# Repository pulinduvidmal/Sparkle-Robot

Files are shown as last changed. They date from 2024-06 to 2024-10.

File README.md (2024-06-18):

# Sparkle Robot ✨🤖

The Sparkle Robot is an advanced automation marvel engineered with the Arduino Mega 2560 at its core. This third-semester project for the EN2533 Robot Design and Competition module showcases a suite of dynamic features that highlight its versatility in robotics engineering.

🚀 **Exciting Robotics Achievement Unlocked: EN2533 Module Conquered!** 🤖

We are delighted to share the successful completion of the EN2533 Robot Design and Competition module in semester 3! 🌟 Our journey was filled with diverse challenges, where my team and I showcased our technical prowess and innovative solutions.

<div style="text-align: center;">
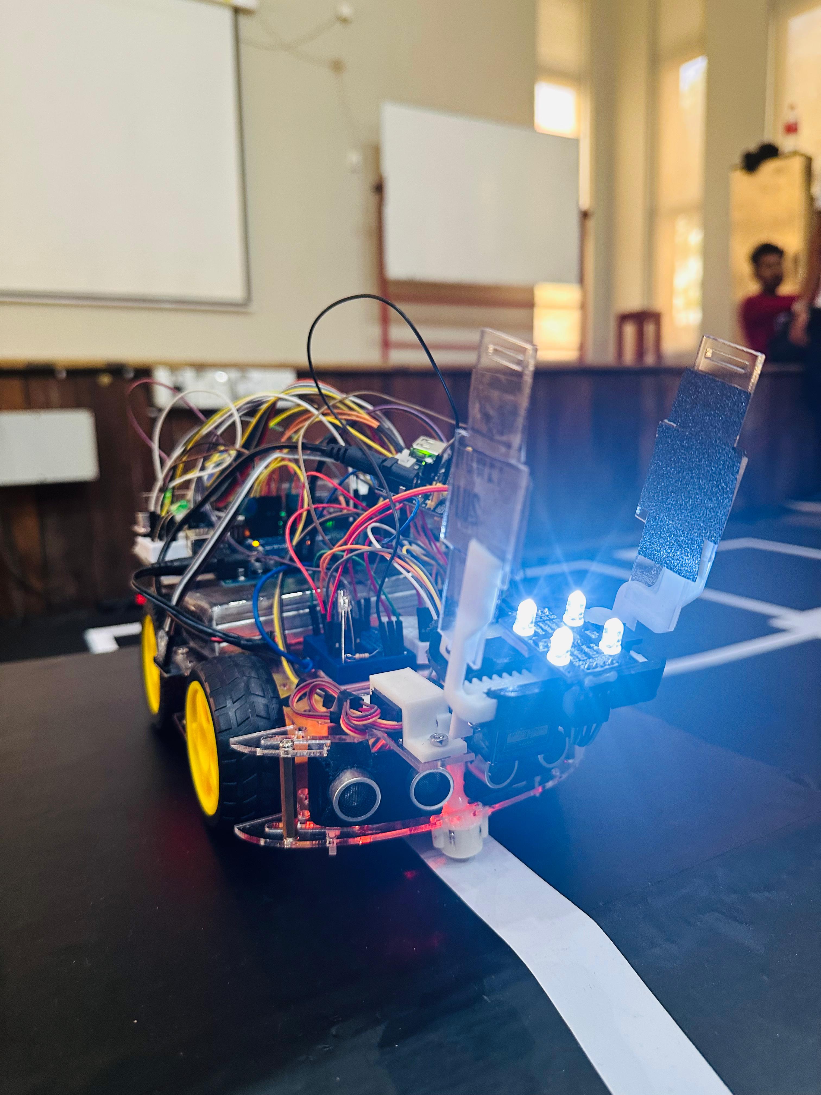
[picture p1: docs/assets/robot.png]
New Image
  
</div>

## Features 🌟

### 1. Line Following and Obstacle Avoidance 🚧
The Sparkle Robot is adept at navigating a designated path with precision. It can follow lines with agility, making sharp turns and avoiding obstacles in its path without human intervention.

### 2. Ramp Navigation & Box Dragging 📦
Demonstrating its mechanical prowess, the robot can traverse inclined surfaces and even engage in box dragging activities. This function highlights the robot's capability to adapt to physical tasks and solve problems autonomously.

### 3. Box Picking and Color Detection 🎨
With an arm engineered in SolidWorks and powered by a servo mechanism, the robot can perform complex picking tasks. It is also equipped with a color sensor strategically positioned to detect and differentiate colors during the pick-up process.

### 4. Maze Solving 🌀
The Sparkle Robot employs a logical approach to navigate mazes. It uses the left-hand rule algorithm to find its way through mazes, identifying the correct path based on the color of the box it carries, and places it accurately in a predetermined location.

### 5. Sound Detection 🎤
Incorporating advanced auditory processing capabilities, the robot can respond to sound cues. This feature allows it to execute precise stops and movements in response to specific sounds, enhancing its interactive abilities.

## Getting Started 🛠️

To get started with the Sparkle Robot, follow these instructions:

1. **Clone the Repository**
   ```bash
   git clone https://github.com/your-username/sparkle-robot.git
   ```

2. **Navigate to the Directory**
   ```bash
   cd sparkle-robot
   ```

3. **Upload the Code to Arduino Mega 2560**
   - Open the Arduino IDE.
   - Load the `sparkle_robot.ino` file.
   - Select the correct board and port.
   - Upload the code.

## Hardware Requirements 🛒

- Arduino Mega 2560
- Line sensors
- Ultrasonic sensors
- Servo motors
- Color sensor
- Sound sensor
- Chassis with wheels
- Box for dragging and picking

## Team Members

- [**Akhila Prabodha**](https://github.com/AkhilaPrabodha)
- [**Pulindu Vidmal**](https://github.com/pulinduvidmal)
- [**Navini Jagoda**](https://github.com/Navini11)
- [**Eshan Surendra**](https://github.com/eshansurendra)
- [**Achira Hansindu**](https://github.com/achira1428gsd)
  
## Demo

https://github.com/pulinduvidmal/Sparkle-Robot/assets/107745680/13c5de56-0cc0-490a-96d4-449374089251

# Contributions 🤝

Contributions are welcome! 

- **Bug Fixes:** If you find any bugs or issues, feel free to create an issue or submit a pull request.
- **Feature Enhancements:** If you have ideas for new features or improvements, don't hesitate to share them.

Feel free to reach out with any questions or suggestions!

# License 📄

This project is licensed under the [MIT License](LICENSE).

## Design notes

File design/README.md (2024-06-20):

## Sparkle- Robot-Design

This folder contains SolidWorks STL files for 3D printing the components of the Sparkle Robot Arm. These files are designed for use with a variety of 3D printing technologies and materials.

**Component Breakdown:**

* **1_hand.STL:** This file represents the first component of the robot hand.
* **2_hand.STL:** This file represents the second component of the robot hand.
* **arm small box.STL:** This file represents a small box situated on the robot arm to keep mechanism with servo motor.
* **wheel final.STL:** This file represents a final version of a wheel component used on the robot arm, for locomotion.

**File Usage:**

* These STL files can be imported into any 3D printing software to prepare for printing.
* Users are encouraged to review the file names and orientations carefully before printing.
* It is recommended to use a slicing software compatible with your 3D printer to prepare the files for printing. 
* Choose appropriate print settings and material based on your printer's capabilities and the desired mechanical properties of the printed parts.

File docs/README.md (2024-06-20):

# Sparkle-Robot 🤖

This repository includes the complete source code, design files, and documentation for the Sparkle Robot, a versatile and feature-rich automation platform built for the EN2533 - Robot Design and Competition module.

<div align="center">
  New Image
</div>

## Features

* **Line Following & Obstacle Avoidance 🚧:** Enables the robot to navigate predefined paths while avoiding obstacles using phototransistors and ultrasonic sensors.
* **Ramp Navigation & Box Dragging 📦:**  A robust mechanical design with a geared motor system enables the robot to ascend ramps and drag boxes.
* **Box Picking & Color Detection 🎨:** A custom SolidWorks-designed robotic arm, powered by a servo motor, allows for precise box picking. A color sensor integrated into the arm enables the robot to differentiate between different colored boxes.
* **Maze Solving 🌀:** Employs a `left-hand rule algorithm`, guided by color sensing, to navigate mazes. The robot utilizes the box color to determine the correct path and destination within a maze environment.
* **Sound Detection 🎤:** Incorporates an audio sensor that allows the robot to detect and respond to specific sound cues, enabling dynamic interactions and programmed actions based on sound triggers.

## Repository Structure

```
├── design
├── docs
│   └── assets
|   └── requirements
├── src
└── scripts
```

**Detailed Description:**

* **design/Robot-Arm-STL:** Contains STL files for 3D printing the robotic arm components designed using SolidWorks.
* **docs**
    * **assets:** Contains supplementary assets for documentation, such as images, diagrams, and videos.
    * **requirements:**  Contains competition requirements documents for the EN2533 module. This folder should include:
        * **Task_v1.pdf:**  The initial version of the competition guidebook.
        * **Task_v1.1.pdf:**  An updated version of the competition guidebook with revisions and clarifications.
* **src:**  contains the Arduino source code for the Sparkle Robot.
    * **sparkle_robot_src.ino:**  The main Arduino program that controls all the robot functionalities.
* **scripts:** Contains scripts for each hardware part of robot for test their funcationality separately.

## Task - 2023

> [!TIP]
> The full task documentation can be found in the [requirements](/docs/requirements/) folder.
> - [Task_V1.0](/docs/requirements/EN2533-Robot_Designand_Competition_Task_v1.0.pdf)
> - [Task_V1.1](/docs/requirements/EN2533-Robot_Design_and_Competition_Task_v1.1.pdf)

<div align="center">
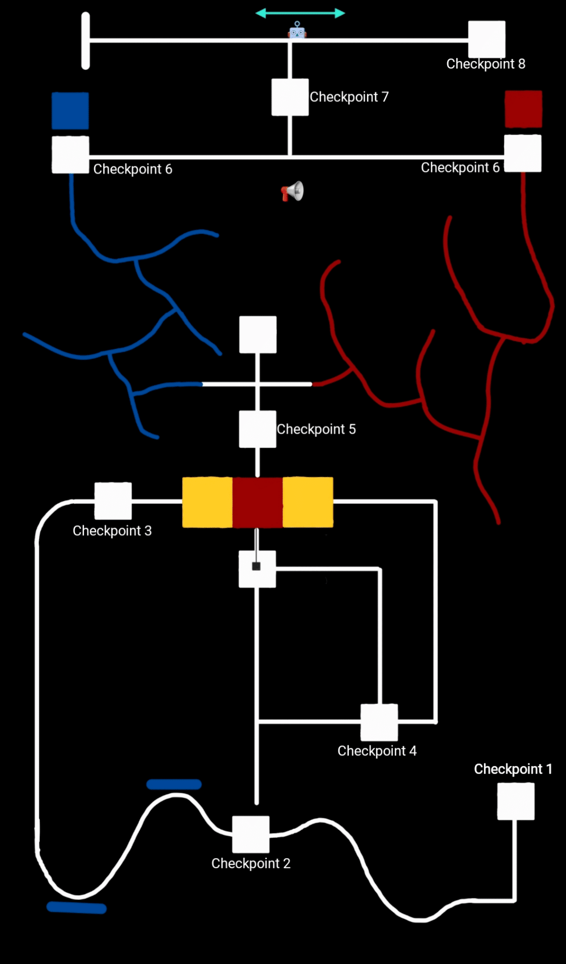
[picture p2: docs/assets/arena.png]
Arena New Image
  
</div>

## Robot overview

### Adding Functionality

* **Line Following:**
    * Implement a line-following algorithm using ir array.
    * Use the analogRead() function to read sensor values.
    * Implement a PID (Proportional-Integral-Derivative) controller to maintain a stable line-following trajectory.
* **Obstacle Avoidance:**
    * Utilize ultrasonic sensors to detect obstacles in front of the robot.
    * Implement a basic obstacle avoidance logic to stop or steer the robot away from detected objects.
* **Ramp Navigation:**
    * Ensure a robust mechanical design that can handle the weight and friction of ascending ramps.
    * Implement a motor control algorithm that can adjust motor speeds to smoothly navigate ramps.
* **Box Dragging:**
    * Design a mechanism that allows the robot to grip and drag boxes without dropping them.
    * Implement a motor control system that can accurately control the speed and direction of the dragging motion.
* **Box Picking & Color Detection:**
    * Design a robotic arm in SolidWorks with appropriate dimensions and articulation.
    * Utilize a servo motor to control the arm movement and gripping mechanism.
    * Integrate a color sensor into the arm's gripping mechanism to detect the color of the box.
* **Maze Solving:**
    * Implement the left-hand rule algorithm to navigate mazes.
    * Use the color sensor to identify the correct path based on the color of the box being carried.
    * Develop logic to determine the correct destination for placing the box.
* **Sound Detection:**
    * Utilize an audio sensor to detect specific sound cues.
    * Implement logic to trigger specific actions or movements based on detected sounds.

### Hardware Requirements

**Sensors:**

* **[Raykha S8 – TCRT5000 based 8 channel Reflective Sensor Array:](https://aptinex.com/product/raykha-s8/)**
    * **Function:** Line detection and color differentiation.
    * **Application:** Line following.
* **[HC-SR04 Ultrasonic Sensors](https://lastminuteengineers.com/arduino-sr04-ultrasonic-sensor-tutorial/):**
    * **Function:** Distance measurement.
    * **Application:** Obstacle detection, object picking, and guarding.
* **[TCS230 RGB Color Recognition Sensor](https://randomnerdtutorials.com/arduino-color-sensor-tcs230-tcs3200/):**
    * **Function:** Color detection and differentiation.
    * **Application:** Competition box object colors identification.
* **[MAX9814 Electret Microphone Amplifier Stable Module with Auto Gain Control](https://www.phippselectronics.com/using-the-max9814-microphone-amplifier-module-with-arduino/):**
    * **Function:** Sound detection and threshold adjustment using [arduinoFFT](https://github.com/kosme/arduinoFFT) library.
    * **Application:** Interactive functionality, event triggering.
* **[MPU6050 Accelerometer and Gyroscope](https://lastminuteengineers.com/mpu6050-accel-gyro-arduino-tutorial/):**
    * **Function:** 3-axis motion tracking.
    * **Application:** Motion tracking, orientation sensing.
      
**Actuators:**

* **DC Gear Motors (34:1 metal gear motors):**
    * **Voltage:** 12V
    * **Application:** Linear motion, driving wheels, and providing torque.
      
* **Servo Motors (MG996R metal gear high torque servo motors):**
    * **Voltage:** 6V
    * **Rotation:** 180 degrees
    * **Application:**  Robotic arm movement, gripping mechanisms, and slider operation.

**Power and Battery:**

* **Battery:** 3S 5200mAh 40C 11.1v LiPo battery.
* **Power Management:**
    * **Step-down buck converter (LM2596S):**  Reduces battery voltage to 9V for motor driver module operation.
    * **Independent buck converter:**  Converts voltage to 5V for sensor functionality.

**Indicators:**

* **LEDs:**  Indicate infrared sensor status and provide visual feedback on sensor operation.

**Other Components:**

* **Power Switch:**  Enables on/off control of the entire robot system.
* **Task-Specific Switches:**  Control activation of specific robot functionalities during competition tasks.

**Robot Arm and Mechanisms:**

* The robot arm is designed in SolidWorks and is powered by a servo motor.
* The arm is responsible for picking up and placing boxes, and it incorporates a color sensor for identifying box colors.
* Gripping mechanisms and slider operations are controlled by servo motors, enabling precise manipulation of objects.

**Software:**

* **[Arduino Mega 2560](https://docs.arduino.cc/hardware/mega-2560/):**  The main microcontroller that controls all robot functionalities.
* **Source Code:**  The code for the Sparkle Robot is located in the `src` folder. The main program file is `sparkle_robot_src.ino`.

> [!TIP]
> Individual hardware components and their functionalities can be independently verified using dedicated test scripts located within the `scripts` folder.

> [!WARNING]
> Modifying hardware component connections or device configurations will inevitably necessitate adjustments to the corresponding pin configurations within the source code or scripts.
## Team Members

- [**Akhila Prabodha**](https://github.com/AkhilaPrabodha)
- [**Pulindu Vidmal**](https://github.com/pulinduvidmal)
- [**Navini Jagoda**](https://github.com/Navini11)
- [**Eshan Surendra**](https://github.com/eshansurendra)
- [**Achira Hansindu**](https://github.com/achira1428gsd)
  
## Demo

https://github.com/pulinduvidmal/Sparkle-Robot/assets/107745680/13c5de56-0cc0-490a-96d4-449374089251

## Contributions

Contributions are welcome! 

- **Bug Fixes:** If you find any bugs or issues, feel free to create an issue or submit a pull request.
- **Feature Enhancements:** If you have ideas for new features or improvements, don't hesitate to share them.

Feel free to reach out with any questions or suggestions!

# License

This project is licensed under the [MIT License](LICENSE).

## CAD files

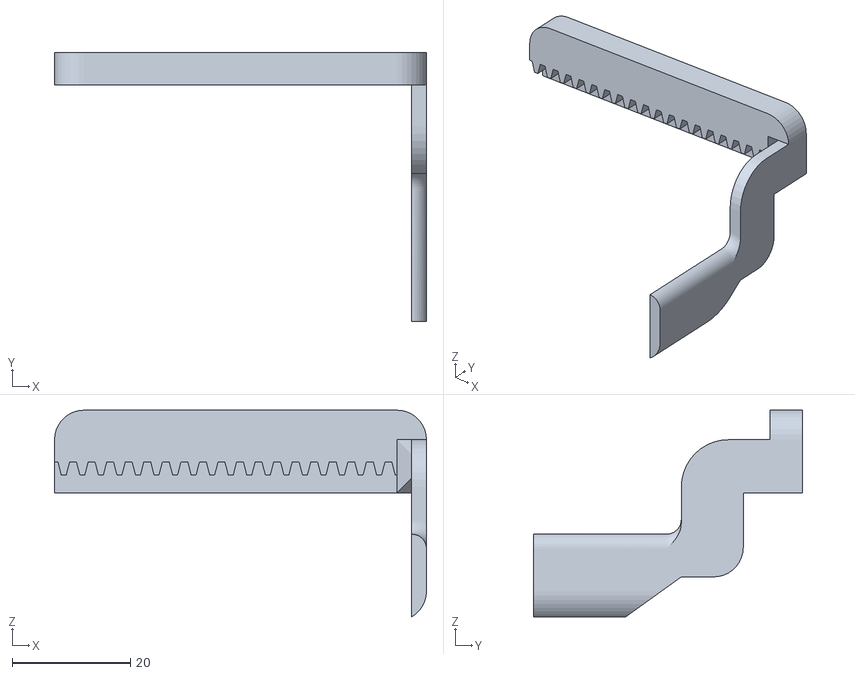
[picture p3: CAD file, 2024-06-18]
design/Robot-Arm-STL/2_hand.STL
63.0 x 45.5 x 35.0

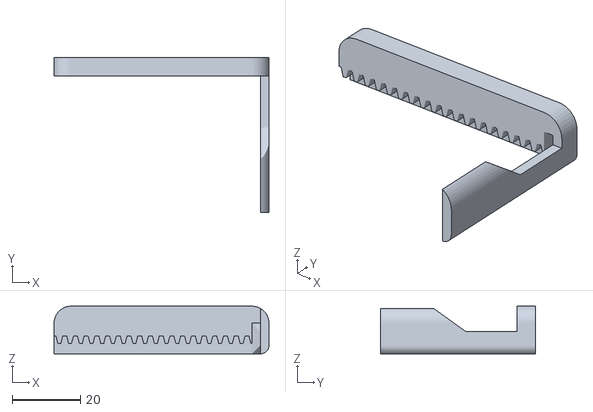
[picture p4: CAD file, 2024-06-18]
design/Robot-Arm-STL/1_hand.STL
63.0 x 45.5 x 14.0

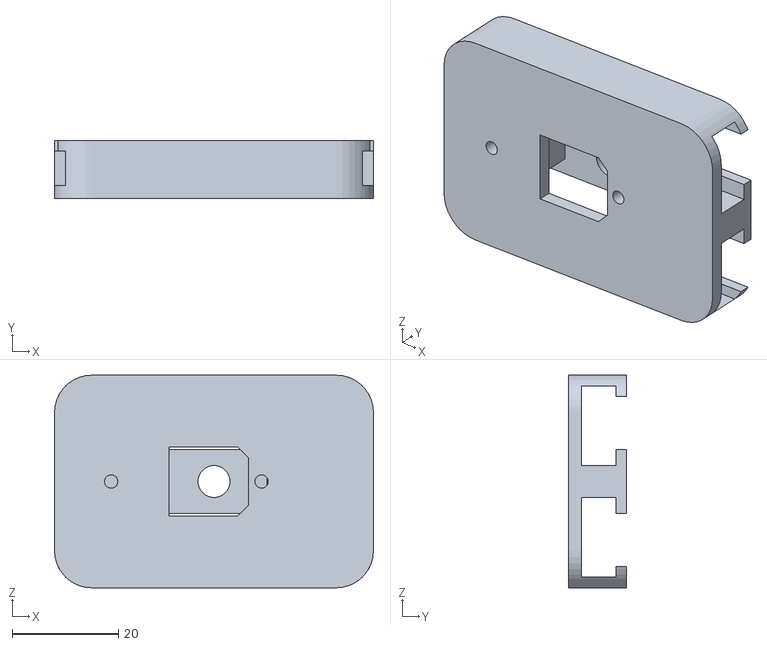
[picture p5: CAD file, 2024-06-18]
design/Robot-Arm-STL/arm small box.STL
60.0 x 11.0 x 40.0

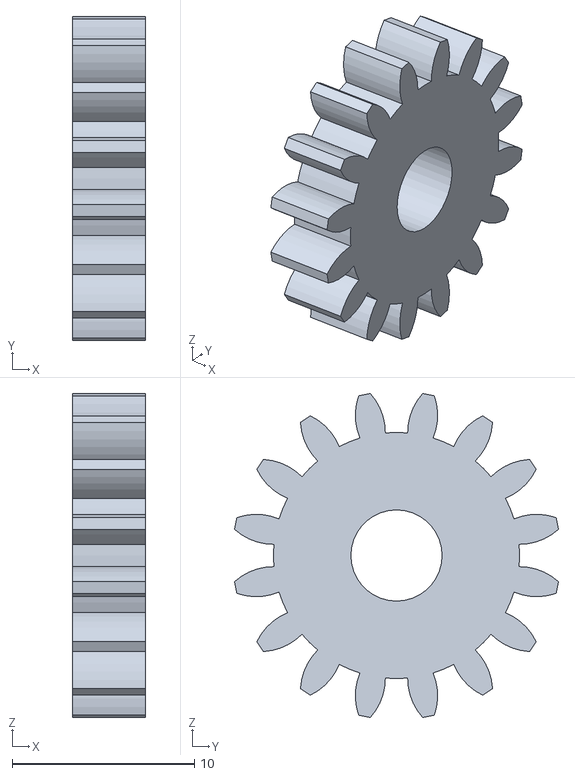
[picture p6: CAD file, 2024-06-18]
design/Robot-Arm-STL/wheel final.STL
4.00 x 17.8 x 17.8

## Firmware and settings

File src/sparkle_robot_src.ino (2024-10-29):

#include <L298N.h>
#include <Arduino.h>
#include <Servo.h>
#include "arduinoFFT.h"

Servo arm;
Servo hand;
arduinoFFT FFT;

//////////////
// Have to redefine those below pins as we plugged
#define AIN1 49
#define BIN1 51
#define AIN2 47
#define BIN2 53
#define PWMA 3
#define PWMB 4
//motor1=right
////////

//ultrasonic sensor read
//////ultrasonic pins
#define lftrig 10
#define lfecho 11
#define rftrig 8
#define rfecho 9

// Initializing motors.  The library will allow you to initialize as many
// motors as you have memory for.  If you are using functions like forward
// that take 2 motors as arguements you can either write new functions or
// call the function more than once.
L298N motor1(PWMA, AIN1, AIN2);
L298N motor2(PWMB, BIN1, BIN2);

// Assign pin numbers to each servo
const int armPin = 12;
const int handPin = 13;

// Constants
const int SensorCount = 8; // Total number of sensors
const int analogSensorCount = 8; // Number of analog sensors
const int analogSensorPins[analogSensorCount] = {A15, A14, A13, A12, A11, A10, A9, A8}; // Analog pins for the remaining sensors
int IR_weight[8] = { -50, -30, -15, -5, 5, 15, 30, 50};
float errorArray[50] = {0};
int sensorValues[SensorCount];

// PID control parameters
float Kp = 4 ; // Proportional term
float Ki = 0; // Integral term
float Kd = 15; // Derivative term
float sum;
int increment_count = 0;
int wall_count = 0;
long ldistance;
long rdistance;

float error;

// PID variables
float P, I, D, previousError = 0;

float lsp, rsp;
int lfspeed = 95;

//////Mic
const int microphonePin = A4;  // Adjust the pin according to your setup

const uint16_t samples = 64;  // This value MUST ALWAYS be a power of 2
const double samplingFrequency = 5000;
const int detectionDuration = 5000;  // Adjust as needed (in milliseconds)

const double detectionMinFrequency = 560;  // Adjust based on your environment
const double detectionMaxFrequency = 600;  // Adjust based on your environment
double averageFrequency;
double currentFrequency;

#define stopLED 39
#define goLED 37

unsigned long lastDetectionTime = 0;

double vReal[samples];
double vImag[samples];

const int maxStoredValues = 30;  // Adjust based on your needs
double storedFrequencies[maxStoredValues];
double storedFrequenciesSub[5];
int storedValuesIndex = 0;
//////////////////////////

// Function prototypes
void readSensors(int *values);
float calculatePID(int *sensorValues);
void motor_drive(int left, int right);
void turnLeft(int *sensorValues);
void turnRight(int *sensorValues);
void noLine();
//Maze
void turnLeft_maze(int *sensorValues);
void turnRight_maze(int *sensorValues);
void noLine_maze();
void maze(int *sensorValues);
void towards_box(int *sensorValues);

void setup() {
  // Initialize analog sensor pins as input
  for (int i = 0; i < analogSensorCount; i++) {
    pinMode(analogSensorPins[i], INPUT);
  }

  // Initialize motor driver pins
  pinMode(PWMA, OUTPUT);
  pinMode(AIN1, OUTPUT);
  pinMode(AIN2, OUTPUT);
  pinMode(PWMB, OUTPUT);
  pinMode(BIN1, OUTPUT);
  pinMode(BIN2, OUTPUT);
  pinMode(23, OUTPUT);
  pinMode(25, OUTPUT);
  pinMode(8, OUTPUT);

  pinMode(lftrig, OUTPUT);
  pinMode(lfecho, INPUT);
  pinMode(rftrig, OUTPUT);
  pinMode(rfecho, INPUT);

  // Start with motors stopped
  motor1.stop();
  motor2.stop();
  digitalWrite(23, LOW);
  digitalWrite(25, LOW);
  //Servo
  arm.attach(armPin);
  hand.attach(handPin);
  zip_mode();

  pinMode(stopLED, OUTPUT);
  pinMode(goLED, OUTPUT);

  digitalWrite(goLED, LOW);
  digitalWrite(stopLED, LOW);

  Serial.begin(9600);
}

void loop() {
  readSensors(sensorValues);
  lUltrasonic_read();
  rUltrasonic_read();
  if (increment_count == 0) {
    if (sensorValues[0] == 1 && sensorValues[1] == 1 && sensorValues[2] == 1 && sensorValues[3] == 1 && sensorValues[4] == 1 && sensorValues[5] == 1 && sensorValues[6] == 1 && sensorValues[7] == 1) {
      increment(sensorValues);
    }
  }
  else if (increment_count == 1) {
    if (sensorValues[0] == 1 && sensorValues[1] == 1 && sensorValues[2] == 1 && sensorValues[3] == 1 && sensorValues[4] == 1 && sensorValues[5] == 1 && sensorValues[6] == 1 && sensorValues[7] == 1) {
      motor1.stop();
      motor2.stop();
      motor1.setSpeed(85);   // Set right motor speed
      motor1.backward();       // Move right motor forward
      motor2.setSpeed(85);   // Set left motor speed
      motor2.forward();
      delay(80);
      motor1.stop();
      motor2.stop();
      increment(sensorValues);
    }
    else {
      line_follow(sensorValues);
    }
  }
  else if (increment_count == 2) {
    if (sensorValues[0] == 1 && sensorValues[1] == 1 && sensorValues[2] == 1 && sensorValues[3] == 1 && sensorValues[4] == 1 && sensorValues[5] == 1 && sensorValues[6] == 1 && sensorValues[7] == 1) {
      increment(sensorValues);
    }
    else {
      wall_follow(sensorValues);
    }
  }
  else if (increment_count == 3) {
    if (sensorValues[0] == 1 && sensorValues[1] == 1 && sensorValues[2] == 1 && sensorValues[3] == 1 && sensorValues[4] == 1 && sensorValues[5] == 1 && sensorValues[6] == 1 && sensorValues[7] == 1) {
      increment(sensorValues);
    }
    else {
      line_follow(sensorValues);
    }
  }
  else if (increment_count == 4) {
    motor1.stop();
    motor2.stop();
    delay(15000);
  }
  else {
    motor1.stop();
    motor2.stop();
    delay(15000);
  }
}

void increment(int *sensorValues) {
  motor1.stop();
  motor2.stop();
  delay(2000);
  white(sensorValues);

}

void increment_back(int *sensorValues) {
  motor1.stop();
  motor2.stop();
  delay(500);
  white_back(sensorValues);

}

void line_follow(int *sensorValues) {
  if (isImmediateTurn(sensorValues)) {
    motor1.stop();
    motor2.stop();
    //digitalWrite(26, HIGH);
    //delay(2000);
    turn(sensorValues);
  }
  else if (sensorValues[0] == 0 && sensorValues[1] == 0 && sensorValues[2] == 0 && sensorValues[3] == 0 && sensorValues[4] == 0 && sensorValues[5] == 0 && sensorValues[6] == 0 && sensorValues[7] == 0) {
    motor1.stop();
    motor2.stop();
    digitalWrite(30, HIGH);
    noLine(sensorValues);
    //digitalWrite(8, LOW);
  }
  else {

    float pidValue = calculatePID(sensorValues);
    PID_Linefollow(pidValue);

    // You may adjust the delay for performance tuning
    digitalWrite(26, LOW);
    digitalWrite(28, HIGH);
    digitalWrite(30, LOW);
  }
}

void line_follow_back(int *sensorValues) {
  if (isImmediateTurn(sensorValues)) {
    motor1.stop();
    motor2.stop();
    digitalWrite(26, HIGH);
    //delay(2000);
    turn(sensorValues);
  }
  else if (sensorValues[0] == 0 && sensorValues[1] == 0 && sensorValues[2] == 0 && sensorValues[3] == 0 && sensorValues[4] == 0 && sensorValues[5] == 0 && sensorValues[6] == 0 && sensorValues[7] == 0) {
    motor1.stop();
    motor2.stop();
    digitalWrite(30, HIGH);
    noLine_back(sensorValues);
    //digitalWrite(8, LOW);
  }
  else {

    float pidValue = calculatePID(sensorValues);
    PID_Linefollow_back(pidValue);

    // You may adjust the delay for performance tuning
    digitalWrite(26, LOW);
    digitalWrite(28, HIGH);
    digitalWrite(30, LOW);
  }
}

void alarm_line_follow(int *sensorValues) {
  lfspeed = 80;
  if (sensorValues[0] == 1 && sensorValues[1] == 1 && sensorValues[2] == 1 && sensorValues[3] == 1 && sensorValues[4] == 1 && sensorValues[5] == 1) {
    motor1.stop();
    motor2.stop();
    motor1.setSpeed(85);   // Set right motor speed
    motor1.forward();       // Move right motor forward
    motor2.setSpeed(85);   // Set left motor speed
    motor2.forward();
    delay(80);
    motor1.stop();
    motor2.stop();
    turnLeft_T(sensorValues);
  }
  else if (sensorValues[0] == 0 && sensorValues[1] == 0 && sensorValues[2] == 1 && sensorValues[3] == 1 && sensorValues[4] == 1 && sensorValues[5] == 1 && sensorValues[6] == 1 && sensorValues[7] == 1) {
    motor1.stop();
    motor2.stop();
    motor1.setSpeed(85);   // Set right motor speed
    motor1.forward();       // Move right motor forward
    motor2.setSpeed(85);   // Set left motor speed
    motor2.forward();
    delay(80);
    turnRight_T(sensorValues);
  }
  else if (sensorValues[0] == 0 && sensorValues[1] == 0 && sensorValues[2] == 0 && sensorValues[3] == 0 && sensorValues[4] == 0 && sensorValues[5] == 0 && sensorValues[6] == 0 && sensorValues[7] == 0) {
    motor1.stop();
    motor2.stop();
    digitalWrite(30, HIGH);
    noLine(sensorValues);
    //digitalWrite(8, LOW);
  }
  else {

    float pidValue = calculatePID(sensorValues);
    PID_Linefollow(pidValue);

    // You may adjust the delay for performance tuning
    digitalWrite(26, LOW);
    digitalWrite(28, HIGH);
    digitalWrite(30, LOW);
  }
}

void wall_follow(int *sensorValues) {
  lUltrasonic_read();
  rUltrasonic_read();
  Kp = 3.75 ; // Proportional term for wall following
  Ki = 0; // Integral term for wall following
  Kd = 15; // Derivative term for wall following
  lfspeed = 77;
  if (wall_count == 2) {
    increment_count += 1;
    Kp = 4 ; // Proportional term
    Ki = 0; // Integral term
    Kd = 15; // Derivative term
    lfspeed = 95;
  }
  if (ldistance < 40 || rdistance < 40) {
    motor1.stop();
    motor2.stop();
    //digitalWrite(26, HIGH);
    delay(1500);
    if (wall_count == 0) {
      wallLeft(sensorValues);
      //delay(2000);
      wallforward(sensorValues);
      motor1.setSpeed(85);   // Set right motor speed
      motor1.forward();       // Move right motor forward
      motor2.setSpeed(85);   // Set left motor speed
      motor2.forward();
      delay(250);
      turnLeft(sensorValues);
      wall_count += 1;
    }
    else if (wall_count == 1) {
      wallRight(sensorValues);
      //delay(2000);
      wallforward(sensorValues);
      motor1.setSpeed(85);   // Set right motor speed
      motor1.forward();       // Move right motor forward
      motor2.setSpeed(85);   // Set left motor speed
      motor2.forward();
      delay(250);
      turnRight(sensorValues);
      wall_count += 1;
    }
  }
  else if (isImmediateTurn(sensorValues)) {
    motor1.stop();
    motor2.stop();
    //delay(2000);
    turn(sensorValues);
    digitalWrite(8, LOW);
  }
  else if (sensorValues[0] == 0 && sensorValues[1] == 0 && sensorValues[2] == 0 && sensorValues[3] == 0 && sensorValues[4] == 0 && sensorValues[5] == 0 && sensorValues[6] == 0 && sensorValues[7] == 0) {
    motor1.stop();
    motor2.stop();
    noLine(sensorValues);
    digitalWrite(8, LOW);
  }
  else {

    float pidValue = calculatePID(sensorValues);
    PID_Linefollow(pidValue);

    // You may adjust the delay for performance tuning
    digitalWrite(26, LOW);
    digitalWrite(28, LOW);
    digitalWrite(30, LOW);
  }
}

void maze(int *sensorValues) {
  lfspeed = 55;
  if (sensorValues[0] == 1 && sensorValues[1] == 1 && sensorValues[2] == 1 && sensorValues[3] == 1 && sensorValues[4] == 1 && sensorValues[5] == 1) {
    motor1.stop();
    motor2.stop();
    motor1.setSpeed(85);   // Set right motor speed
    motor1.forward();       // Move right motor forward
    motor2.setSpeed(85);   // Set left motor speed
    motor2.forward();
    delay(80);
    motor1.stop();
    motor2.stop();
    readSensors(sensorValues);
    if (sensorValues[0] == 1 && sensorValues[1] == 1 && sensorValues[2] == 1 && sensorValues[3] == 1 && sensorValues[4] == 1 && sensorValues[5] == 1 && sensorValues[6] == 1 && sensorValues[7] == 1) {
      motor1.stop();
      motor2.stop();
      delay(80);
      increment_count += 1;
    }
    else {
      turnLeft_T(sensorValues);
      turnLeft(sensorValues);
      motor1.stop();
      motor2.stop();
      delay(80);
      motor1.setSpeed(85);   // Set right motor speed
      motor1.backward();       // Move right motor forward
      motor2.setSpeed(85);   // Set left motor speed
      motor2.backward();
      delay(250);
    }
  }
  else if (sensorValues[0] == 0 && sensorValues[1] == 0 && sensorValues[2] == 1 && sensorValues[3] == 1 && sensorValues[4] == 1 && sensorValues[5] == 1 && sensorValues[6] == 1 && sensorValues[7] == 1) {
    motor1.stop();
    motor2.stop();
    motor1.setSpeed(85);   // Set right motor speed
    motor1.forward();       // Move right motor forward
    motor2.setSpeed(85);   // Set left motor speed
    motor2.forward();
    delay(120);
    motor1.stop();
    motor2.stop();
    readSensors(sensorValues);
    if (sensorValues[0] == 0 && sensorValues[1] == 0 && sensorValues[2] == 0 && sensorValues[3] == 0 && sensorValues[4] == 0 && sensorValues[5] == 0 && sensorValues[6] == 0 && sensorValues[7] == 0) {
      turnRight_T(sensorValues);
      turnRight(sensorValues);
      motor1.stop();
      motor2.stop();
      delay(80);
      motor1.setSpeed(85);   // Set right motor speed
      motor1.backward();       // Move right motor forward
      motor2.setSpeed(85);   // Set left motor speed
      motor2.backward();
      delay(250);
      maze(sensorValues);
    }
    else {
      maze(sensorValues);
    }
  }
  else if (sensorValues[0] == 0 && sensorValues[1] == 0 && sensorValues[2] == 0 && sensorValues[3] == 0 && sensorValues[4] == 0 && sensorValues[5] == 0 && sensorValues[6] == 0 && sensorValues[7] == 0) {
    motor1.stop();
    motor2.stop();
    digitalWrite(30, HIGH);
    noLine_maze(sensorValues);
    //digitalWrite(8, LOW);
  }
  else {

    float pidValue = calculatePID(sensorValues);
    PID_Linefollow(pidValue);

    // You may adjust the delay for performance tuning
    digitalWrite(26, LOW);
    digitalWrite(28, LOW);
    digitalWrite(30, LOW);
  }
}

void alarm_path(int *sensorValues) {
  Serial.println(currentFrequency);
  Serial.println(averageFrequency);
  frequencyValue(storedFrequencies);
  calculateArrayAverage(storedFrequencies, maxStoredValues);
  if ((currentFrequency >= detectionMinFrequency && currentFrequency <= detectionMaxFrequency)) {
    motor1.stop();
    motor2.stop();
  }
  else if (!(averageFrequency >= detectionMinFrequency && averageFrequency <= detectionMaxFrequency)) {
    alarm_line_follow(sensorValues);
  }
}

void task_4_begin(int *sensorValues) {
  if (sensorValues[0] == 1 && sensorValues[1] == 1 && sensorValues[2] == 1 && sensorValues[3] == 1 && sensorValues[4] == 1 && sensorValues[5] == 1 && sensorValues[6] == 1 && sensorValues[7] == 1) {
    bool whitedetect = sensorValues[0] == 1 && sensorValues[1] == 1 && sensorValues[2] == 1 && sensorValues[3] == 1 && sensorValues[4] == 1 && sensorValues[5] == 1 && sensorValues[6] == 1 && sensorValues[7] == 1;
    while (whitedetect) {
      sensorValues[SensorCount];
      readSensors(sensorValues);
      whitedetect = sensorValues[0] == 1 && sensorValues[1] == 1 && sensorValues[2] == 1 && sensorValues[3] == 1 && sensorValues[4] == 1 && sensorValues[5] == 1 && sensorValues[6] == 1 && sensorValues[7] == 1;
      if (!whitedetect) {
        break;
      }
      motor1.setSpeed(90);   // Set right motor speed
      motor1.forward();       // Move right motor forward
      motor2.setSpeed(90);   // Set left motor speed
      motor2.forward();      // Move left motor backward for a sharper turn
    }
    motor1.stop();
    motor2.stop();
    delay(200);
    increment_count += 1;
  }
  else {
    line_follow(sensorValues);
  }
}

void towards_box(int *sensorValues) {
  lfspeed = 70;
  if (ldistance < 14 || rdistance < 14) {
    motor1.stop();
    motor2.stop();
    digitalWrite(26, HIGH);
    delay(2000);
    digitalWrite(26, LOW);
    increment_count += 1;
  }
  else if (isImmediateTurn(sensorValues)) {
    motor1.stop();
    motor2.stop();
    //delay(2000);
    turn(sensorValues);
    digitalWrite(8, LOW);
  }
  else if (sensorValues[0] == 0 && sensorValues[1] == 0 && sensorValues[2] == 0 && sensorValues[3] == 0 && sensorValues[4] == 0 && sensorValues[5] == 0 && sensorValues[6] == 0 && sensorValues[7] == 0) {
    motor1.stop();
    motor2.stop();
    noLine(sensorValues);
    digitalWrite(8, LOW);
  }
  else {

    float pidValue = calculatePID(sensorValues);
    PID_Linefollow(pidValue);

    // You may adjust the delay for performance tuning
    digitalWrite(26, LOW);
    digitalWrite(28, LOW);
    digitalWrite(30, LOW);
  }
}

void box_picking() {
  delay(2000);
  servo_down();
  delay(2000);
  motor1.setSpeed(80);   // Set right motor speed
  motor1.forward();       // Move right motor forward
  motor2.setSpeed(80);   // Set left motor speed
  motor2.forward();
  delay(500);
  motor1.stop();
  motor2.stop();
  delay(500);
  pick_the_box();
  increment_count += 1;
}

void task_4_position(int *sensorValues) {
  if (sensorValues[0] == 1 && sensorValues[1] == 1 && sensorValues[2] == 1 && sensorValues[3] == 1 && sensorValues[4] == 1 && sensorValues[5] == 1 && sensorValues[6] == 1 && sensorValues[7] == 1) {
    bool whitedetect = sensorValues[0] == 1 && sensorValues[1] == 1 && sensorValues[2] == 1 && sensorValues[3] == 1 && sensorValues[4] == 1 && sensorValues[5] == 1 && sensorValues[6] == 1 && sensorValues[7] == 1;
    while (whitedetect) {
      sensorValues[SensorCount];
      readSensors(sensorValues);
      whitedetect = sensorValues[0] == 1 && sensorValues[1] == 1 && sensorValues[2] == 1 && sensorValues[3] == 1 && sensorValues[4] == 1 && sensorValues[5] == 1 && sensorValues[6] == 1 && sensorValues[7] == 1;
      if (!whitedetect) {
        break;
      }
      motor1.setSpeed(70);   // Set right motor speed
      motor1.backward();       // Move right motor forward
      motor2.setSpeed(70);   // Set left motor speed
      motor2.backward();      // Move left motor backward for a sharper turn
    }
    motor1.stop();
    motor2.stop();
    delay(200);
    increment_count += 1;
  }
  else {
    increment_count += 1;
  }
}
void task_4_back(int *sensorValues) {
  if (sensorValues[0] == 1 && sensorValues[1] == 1 && sensorValues[2] == 1 && sensorValues[3] == 1 && sensorValues[4] == 1 && sensorValues[5] == 1 && sensorValues[6] == 1 && sensorValues[7] == 1) {
    motor1.stop();
    motor2.stop();
    delay(2000);
    increment_count += 1;
  }
  else {
    motor1.setSpeed(80);   // Set right motor speed
    motor1.backward();       // Move right motor forward
    motor2.setSpeed(80);   // Set left motor speed
    motor2.backward();      // Move left motor backward for a sharper turn
  }
}

void pathselection(int *sensorValues) {
  lfspeed = 80;
  delay(200);
  if (sensorValues[0] == 0 && sensorValues[1] == 0 && sensorValues[2] == 1 && sensorValues[3] == 1 && sensorValues[4] == 1 && sensorValues[5] == 1 && sensorValues[6] == 0 && sensorValues[7] == 0) {
    motor1.stop();
    motor2.stop();
    increment_count += 1;
    delay(200);
  }
  else {
    line_follow(sensorValues);
  }
}

void readSensors(int *values) {
  // Read analog sensors
  for (int i = 0; i < analogSensorCount; i++) {
    values[i] = analogRead(analogSensorPins[i]) > 135 ? 0 : 1; // Assuming higher values indicate no line
  }
}

float calculatePID(int *sensorValues) {
  float position = 0;
  int onLine = 0;

  // Loop through all sensors
  for (int i = 0; i < SensorCount; i++) {
    if (sensorValues[i] == 1) { // Assuming 1 indicates line detected
      position += IR_weight[(i)];
      onLine++;
    }
  }

  // If no line is detected by any sensor, use the last known error value
  if (onLine == 0) {
    // If previous error is not available, assume the line is straight ahead
    error = -previousError;
  }
  else {
    // Calculate the average position of the line
    position /= onLine;
    // Calculate error based on sensor position
    error = 0 - position;
  }
  for (int i = 49; i > 0; i--) {
    errorArray[i] = errorArray[i - 1];
  }
  errorArray[0] = error;
  // PID terms
  P = error;
  I += error;
  D = error - previousError;
  previousError = error;

  // Calculate PID value
  float pidValue = (Kp * P) + (Ki * I) + (Kd * D);


  return pidValue;
}

void PID_Linefollow(float pidValue) {
  lsp = lfspeed - pidValue;
  rsp = lfspeed + pidValue;

  if (lsp > 255) {
    lsp = 255;
  }
  if (lsp < -255) {
    lsp = -255;
  }
  if (rsp > 255) {
    rsp = 255;
  }
  if (rsp < -255) {
    rsp = 255;
  }
  motor_drive(lsp, rsp);
}

void motor_drive(float left, float right) {
  int absRight = abs(right); // Absolute value for right speed
  int absLeft = abs(left);   // Absolute value for left speed

  if (left > 0) {
    motor2.setSpeed(absLeft);
    motor2.forward();
  } else {
    motor2.setSpeed(absLeft);
    motor2.backward();
  }

  if (right > 0) {
    motor1.setSpeed(absRight);
    motor1.forward();
  } else {
    motor1.setSpeed(absRight);
    motor1.backward();
  }
}

void PID_Linefollow_back(float pidValue) {
  lsp = lfspeed - pidValue;
  rsp = lfspeed + pidValue;

  if (lsp > 255) {
    lsp = 255;
  }
  if (lsp < -255) {
    lsp = -255;
  }
  if (rsp > 255) {
    rsp = 255;
  }
  if (rsp < -255) {
    rsp = 255;
  }
  motor_drive_back(lsp, rsp);
}

void motor_drive_back(float left, float right) {
  int absRight = abs(right); // Absolute value for right speed
  int absLeft = abs(left);   // Absolute value for left speed

  if (left < 0) {
    motor2.setSpeed(absLeft);
    motor2.forward();
  } else {
    motor2.setSpeed(absLeft);
    motor2.backward();
  }

  if (right < 0) {
    motor1.setSpeed(absRight);
    motor1.forward();
  } else {
    motor1.setSpeed(absRight);
    motor1.backward();
  }
}

bool isImmediateTurn(int *sensorValues) {
  bool turnLeft = sensorValues[0] == 1 && sensorValues[1] == 1 && sensorValues[2] == 1 && sensorValues[3] == 1 && sensorValues[4] == 1 && sensorValues[5] == 1;
  bool turnRight = sensorValues[2] == 1 && sensorValues[3] == 1 && sensorValues[4] == 1 && sensorValues[5] == 1 && sensorValues[6] == 1 && sensorValues[7] == 1;
  return (turnLeft || turnRight);
}
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

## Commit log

2024-06-18 Update and rename Stage_01.ino to Stage_01.ino
2024-06-20 add design folder
    [1_hand.STL, 2_hand.STL, arm small box.STL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]
2024-06-20 Update and rename Stage_01.ino to sparkle_robot_src.ino
